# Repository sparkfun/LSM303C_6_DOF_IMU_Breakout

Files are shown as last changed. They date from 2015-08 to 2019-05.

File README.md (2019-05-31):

SparkFun LSM303C 6 DOF IMU Breakout
========================================

LSM303C Breakout (https://www.sparkfun.com/products/13303)

*[SparkFun LSM303C 6 DOF IMU Breakout (BOB-13303)](https://www.sparkfun.com/products/13303)*

The LSM303C is a triple axis accelerometer and triple axis magnetic sensor, providing 6D of orientation detection.

This part was created in Eagle v7.4.0

Repository Contents
-------------------

* **/Hardware** - All Eagle design files (.brd, .sch)
* **/Libraries** - All Arduino libraries and board examples
* **/Production** - Test bed files and production panel files

Documentation
--------------
* **[Arduino Library](https://github.com/sparkfun/SparkFun_LSM303C_6_DOF_IMU_Breakout_Arduino_Library)** - Arduino library for the LSM303C.
* **[Hookup Guide](https://learn.sparkfun.com/tutorials/lsm303c-6dof-hookup-guide)** - Basic hookup guide for the LSM303C.
* **[SparkFun Fritzing repo](https://github.com/sparkfun/Fritzing_Parts)** - Fritzing diagrams for SparkFun products.
* **[SparkFun 3D Model repo](https://github.com/sparkfun/3D_Models)** - 3D models of SparkFun products. 
* **[SparkFun Graphical Datasheets](https://github.com/sparkfun/Graphical_Datasheets)** -Graphical Datasheets for various SparkFun products

Product Versions
----------------
* [BOB-13303](https://www.sparkfun.com/products/13303)- LSM303C based 6 DOF IMU beakout board

Version History
---------------
* [v1.0_H1.0](https://github.com/sparkfun/LSM303C_6_DOF_IMU_Breakout/releases/tag/v1.0_H1.0) - Removing old libraries. Adding links to formal libs in readme.
* [v1.0](https://github.com/sparkfun/LSM303C_6_DOF_IMU_Breakout/releases/tag/v1.0) - First (hopefully ony) product release.  v10 is SFE code for version 1.0

License Information
-------------------

This product is _**open source**_! 

Please review the LICENSE.md file for license information. 

If you have any questions or concerns on licensing, please contact techsupport@sparkfun.com.

Distributed as-is; no warranty is given.

- Your friends at SparkFun.

_<COLLABORATION CREDIT>_

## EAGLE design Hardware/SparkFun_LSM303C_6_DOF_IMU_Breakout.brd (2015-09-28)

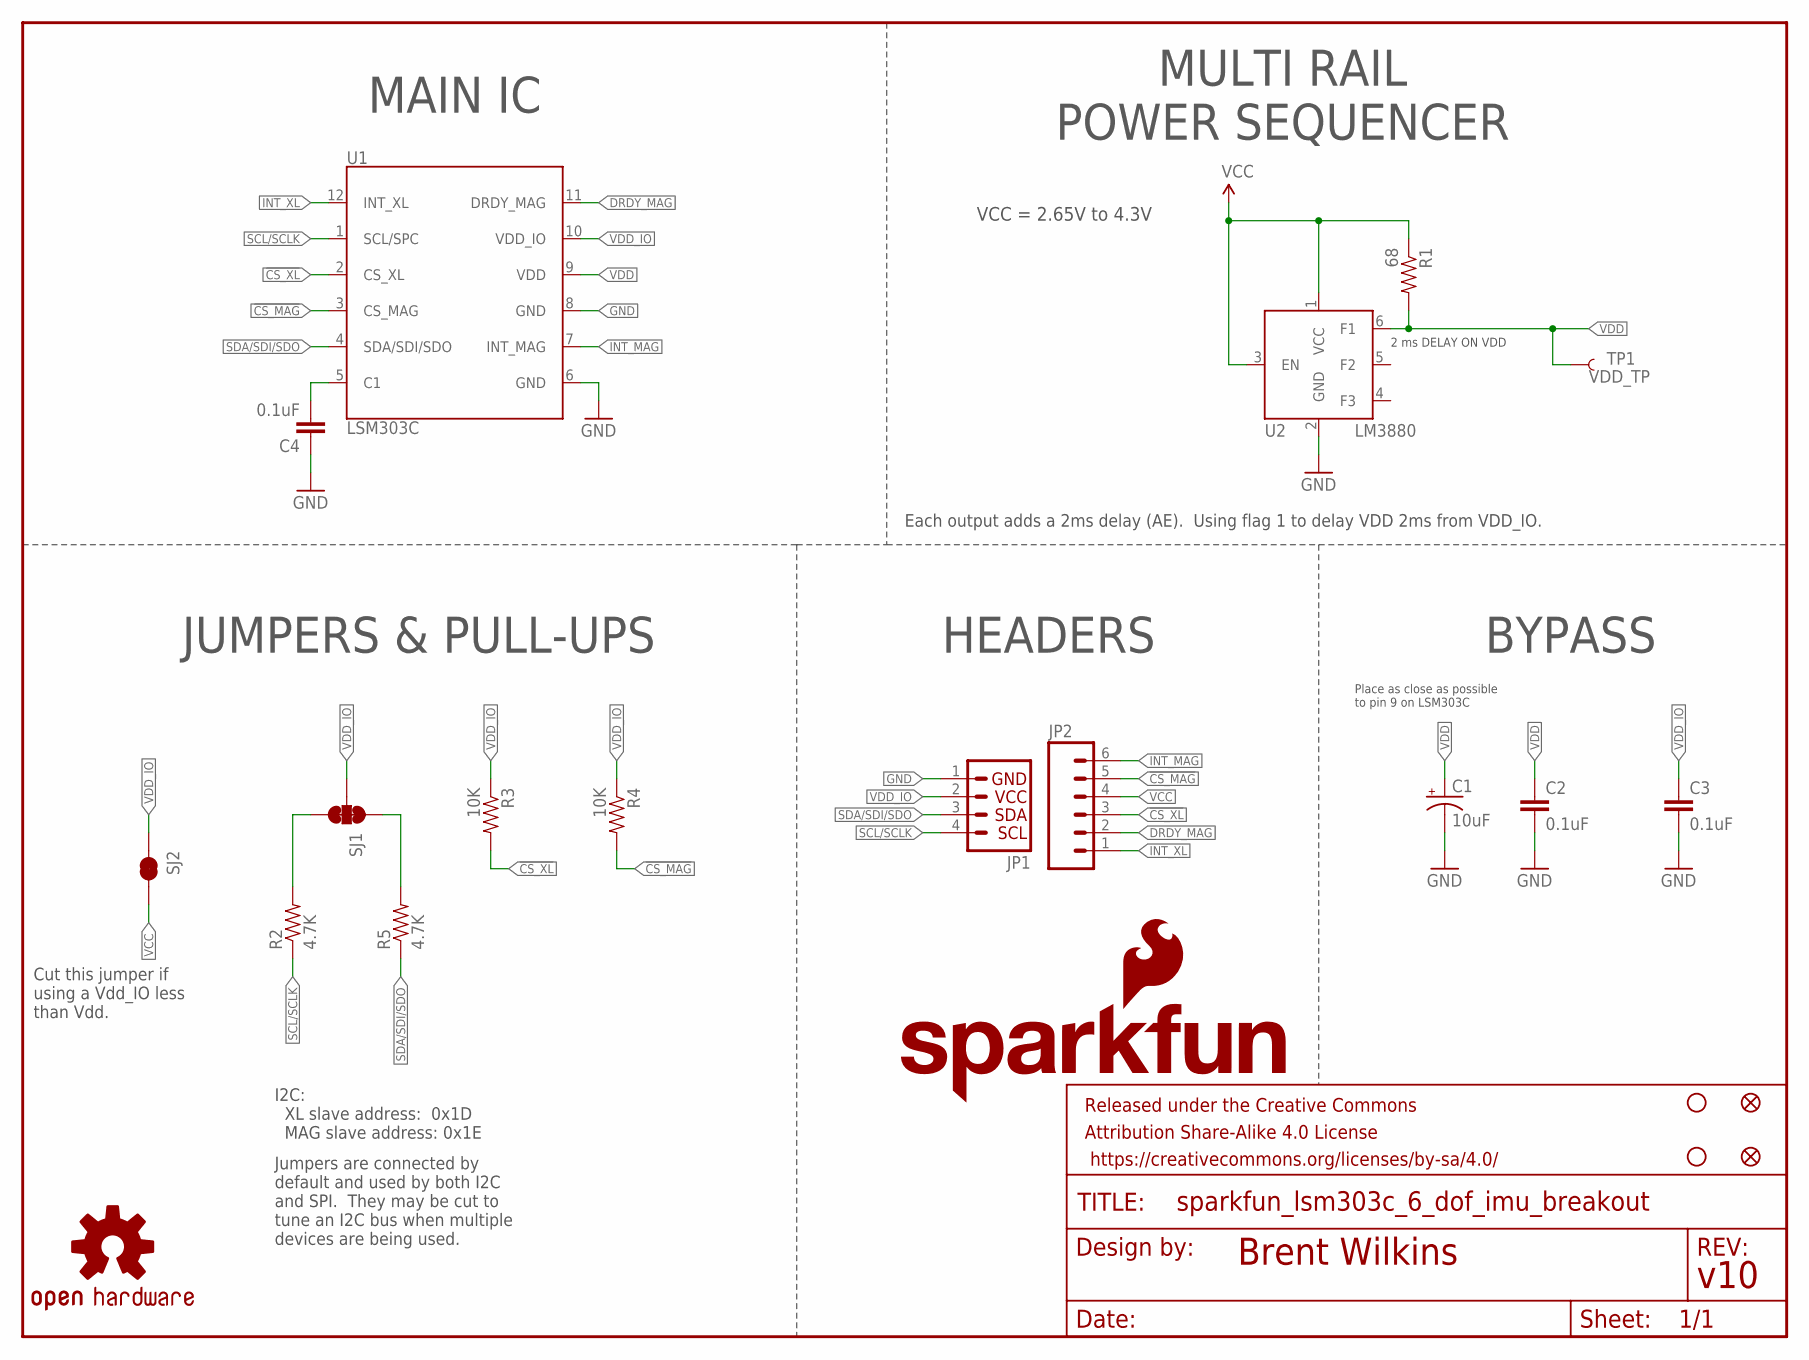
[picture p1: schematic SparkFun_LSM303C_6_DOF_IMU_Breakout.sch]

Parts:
C1: 10uF; EIA3216
C2, C3, C4: 0.1uF; 0603-CAP
FID1, FID2: FIDUCIAL1X2; FIDUCIAL-1X2
FRAME1: FRAME-LETTER; CREATIVE_COMMONS
JP1: I2C_STANDARD; 1X04
JP2: M06SILK_FEMALE_PTH; 1X06
LOGO1: SFE_LOGO_NAME.1_INCH; SFE_LOGO_NAME_.1
LOGO2: SFE_LOGO_FLAME.1EXP; SFE_LOGO_FLAME_COPPER_EXPOSED_.1
R1: 68; 0603-RES
R2, R5: 4.7K; 0603-RES
R3, R4: 10K; 0603-RES
SJ1: JUMPER-PAD-3-NC_BY_TRACE; PAD-JUMPER-3-3OF3_NC_BY_TRACE_YES_SILK_FULL_BOX
SJ2: JUMPER-PAD-2-NC_BY_TRACE; PAD-JUMPER-2-NC_BY_TRACE_YES_SILK
STANDOFF1, STANDOFF2: STAND-OFF
TP1: VDD_TP; TP_15TH
U1: LSM303C; LGA-12
U2: LM3880; SOT23-6
U$8: OSHW-LOGOS; OSHW-LOGO-S

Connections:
!CS_MAG: JP2.5, R4.2, U1.3 (CS_MAG)
!CS_XL: JP2.3, R3.2, U1.2 (CS_XL)
DRDY_MAG: JP2.2, U1.11 (DRDY_MAG)
GND: C1.C (-), C2.2, C3.2, C4.1, JP1.1, U1.6 (GND), U1.8 (GND), U2.2 (GND)
I2C-UP: R5.2, SJ1.1
INT_MAG: JP2.6, U1.7 (INT_MAG)
INT_XL: JP2.1, U1.12 (INT_XL)
unnamed: C4.2, U1.5 (C1)
unnamed: R2.2, SJ1.3
SCL/SCLK: JP1.4, R2.1, U1.1 (SCL/SPC)
SDA/SDI/SDO: JP1.3, R5.1, U1.4 (SDA/SDI/SDO)
VCC: JP2.4, R1.1, SJ2.2, U2.1 (VCC), U2.3 (EN)
VDD: C1.A (+), C2.1, R1.2, TP1.P$1, U1.9 (VDD), U2.6 (F1)
VDD_IO: C3.1, JP1.2, R3.1, R4.1, SJ1.2, SJ2.1, U1.10 (VDD_IO)

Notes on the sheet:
2 ms DELAY ON VDD
Place as close as possible to pin 9 on LSM303C
I2C: XL slave address: 0x1D MAG slave address: 0x1E
JUMPERS & PULL-UPS
HEADERS
BYPASS
MULTI RAIL POWER SEQUENCER
MAIN IC
Each output adds a 2ms delay (AE). Using flag 1 to delay VDD 2ms from VDD_IO.
Cut this jumper if using a Vdd_IO less than Vdd.
Jumpers are connected by default and used by both I2C and SPI. They may be cut to tune an I2C bus when multiple devices are being used.
VCC = 2.65V to 4.3V

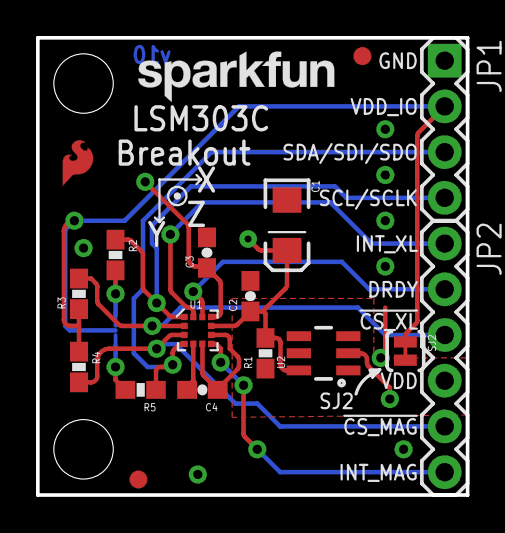
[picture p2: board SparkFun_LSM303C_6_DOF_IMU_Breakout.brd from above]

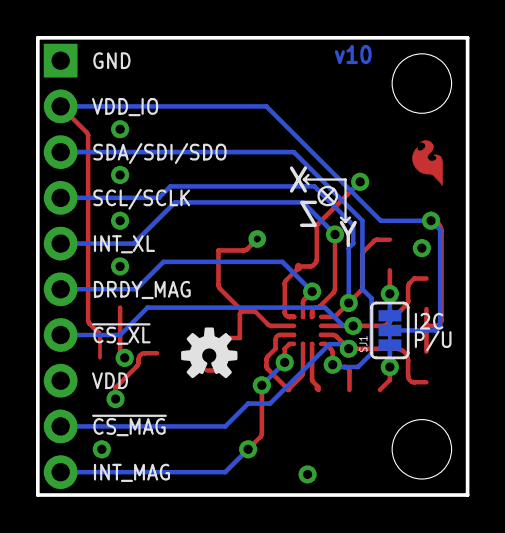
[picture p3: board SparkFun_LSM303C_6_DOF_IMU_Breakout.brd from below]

Board: 2 copper layers, 23.9 x 25.4 mm, 24 parts (2 on the bottom side), 14 nets.

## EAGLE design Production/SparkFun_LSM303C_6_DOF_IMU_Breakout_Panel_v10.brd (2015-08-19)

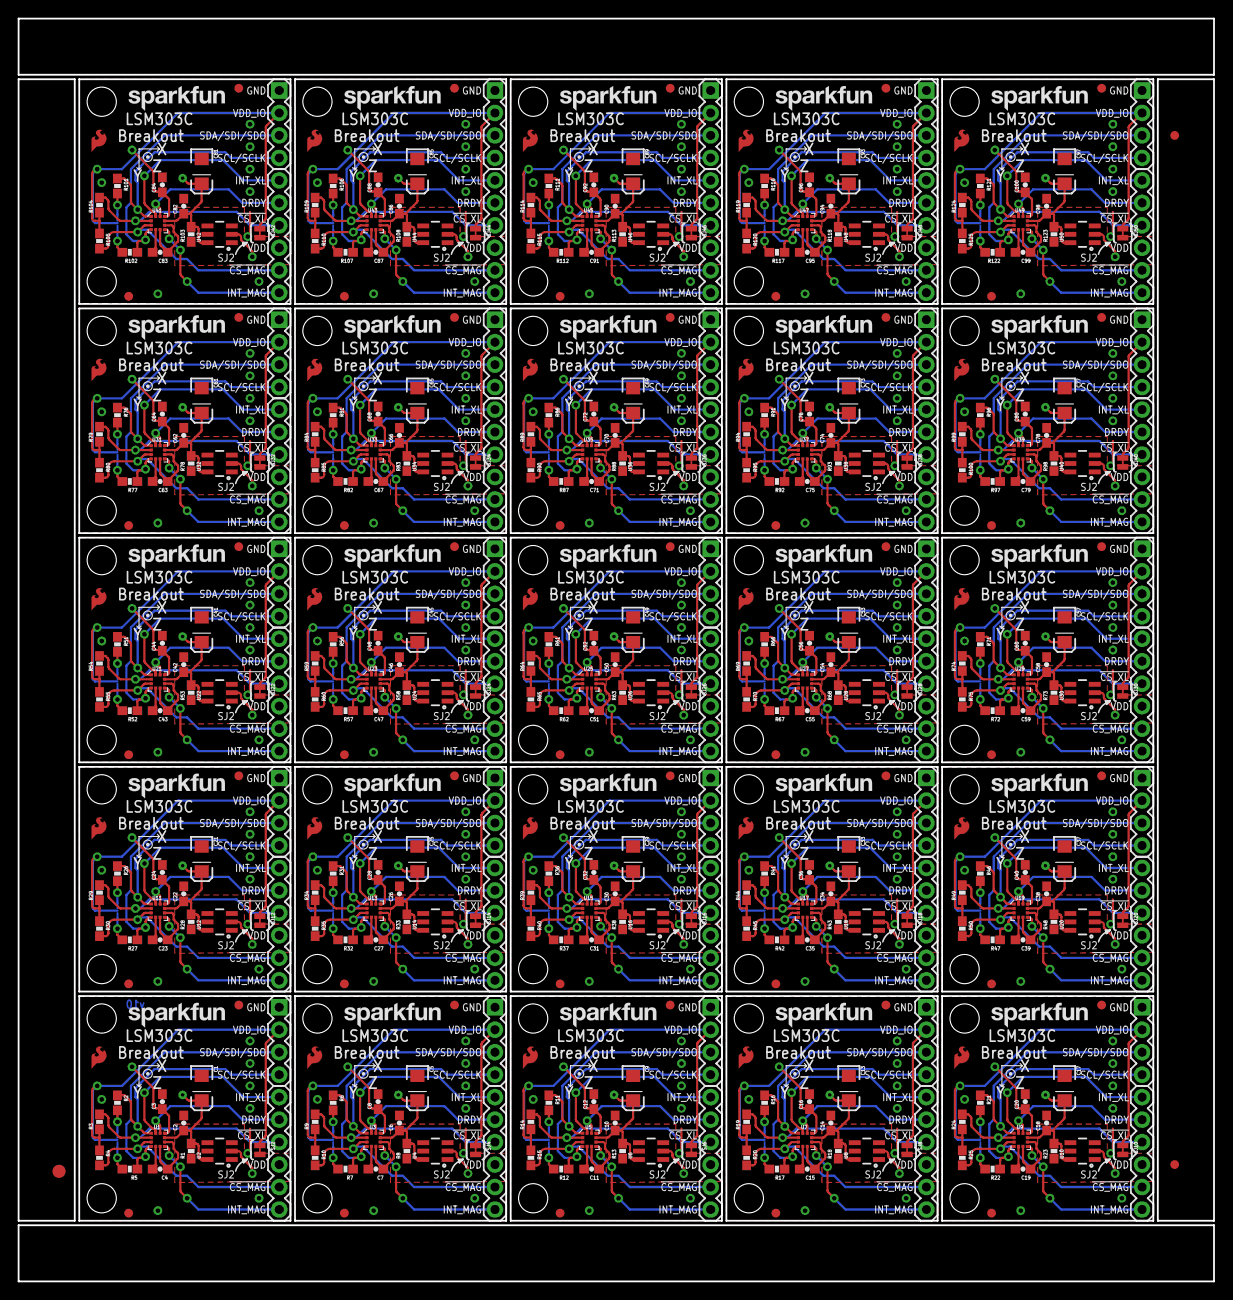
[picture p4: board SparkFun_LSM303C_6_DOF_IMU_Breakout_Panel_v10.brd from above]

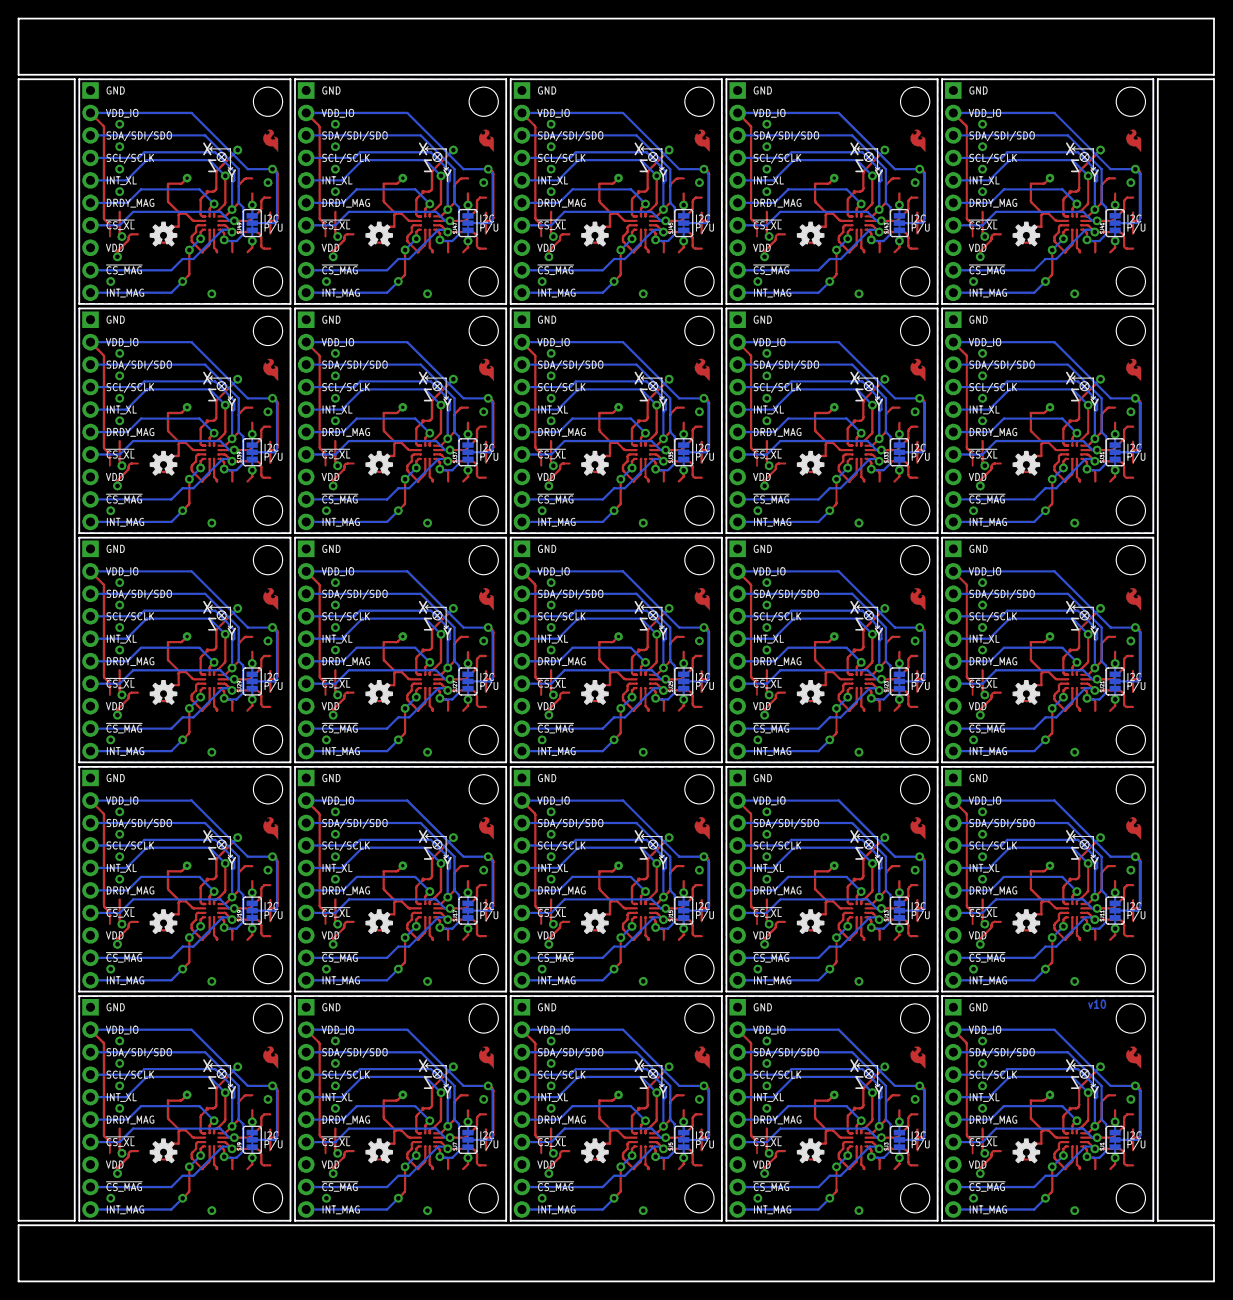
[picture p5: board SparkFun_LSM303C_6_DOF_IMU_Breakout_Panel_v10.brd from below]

Board: 2 copper layers, 135.1 x 142.7 mm, 578 parts (50 on the bottom side), 350 nets.

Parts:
C1, C5, C9, C13, C17, C21, C25, C29, C33, C37, C41, C45, C49, C53, C57, C61, C65, C69, C73, C77, C81, C85, C89, C93, C97: 10uF; EIA3216
C2, C3, C4, C6, C7, C8, C10, C11, C12, C14, C15, C16, C18, C19, C20, C22, C23, C24, C26, C27, C28, C30, C31, C32, C34, C35, C36, C38, C39, C40, C42, C43, C44, C46, C47, C48, C50, C51, C52, C54, C55, C56, C58, C59, C60, C62, C63, C64, C66, C67, C68, C70, C71, C72, C74, C75, C76, C78, C79, C80, C82, C83, C84, C86, C87, C88, C90, C91, C92, C94, C95, C96, C98, C99, C100: 0.1uF; 0603-CAP
E$1: FIDUCIAL-1.5X3
E$4, E$5: FIDUCIAL-1X2
FID1, FID2, FID3, FID4, FID5, FID6, FID7, FID8, FID9, FID10, FID11, FID12, FID13, FID14, FID15, FID16, FID17, FID18, FID19, FID20, FID21, FID22, FID23, FID24, FID25, FID26, FID27, FID28, FID29, FID30, FID31, FID32, FID33, FID34, FID35, FID36, FID37, FID38, FID39, FID40, FID41, FID42, FID43, FID44, FID45, FID46, FID47, FID48, FID49, FID50: FIDUCIAL1X2; FIDUCIAL-1X2
JP1, JP4, JP6, JP8, JP10, JP12, JP14, JP16, JP18, JP20, JP22, JP24, JP26, JP28, JP30, JP32, JP34, JP36, JP38, JP40, JP42, JP44, JP46, JP48, JP50: 1X04
JP2, JP3, JP5, JP7, JP9, JP11, JP13, JP15, JP17, JP19, JP21, JP23, JP25, JP27, JP29, JP31, JP33, JP35, JP37, JP39, JP41, JP43, JP45, JP47, JP49: 1X06
LOGO1, LOGO3, LOGO5, LOGO7, LOGO9, LOGO11, LOGO13, LOGO15, LOGO17, LOGO19, LOGO21, LOGO23, LOGO25, LOGO27, LOGO29, LOGO31, LOGO33, LOGO35, LOGO37, LOGO39, LOGO41, LOGO43, LOGO45, LOGO47, LOGO49: SFE_LOGO_NAME.1_INCH; SFE_LOGO_NAME_.1
LOGO2, LOGO4, LOGO6, LOGO8, LOGO10, LOGO12, LOGO14, LOGO16, LOGO18, LOGO20, LOGO22, LOGO24, LOGO26, LOGO28, LOGO30, LOGO32, LOGO34, LOGO36, LOGO38, LOGO40, LOGO42, LOGO44, LOGO46, LOGO48, LOGO50: SFE_LOGO_FLAME.1EXP; SFE_LOGO_FLAME_COPPER_EXPOSED_.1
R1, R8, R13, R18, R23, R28, R33, R38, R43, R48, R53, R58, R63, R68, R73, R78, R83, R88, R93, R98, R103, R108, R113, R118, R123: 68; 0603-RES
R2, R5, R6, R7, R11, R12, R16, R17, R21, R22, R26, R27, R31, R32, R36, R37, R41, R42, R46, R47, R51, R52, R56, R57, R61, R62, R66, R67, R71, R72, R76, R77, R81, R82, R86, R87, R91, R92, R96, R97, R101, R102, R106, R107, R111, R112, R116, R117, R121, R122: 4.7K; 0603-RES
R3, R4, R9, R10, R14, R15, R19, R20, R24, R25, R29, R30, R34, R35, R39, R40, R44, R45, R49, R50, R54, R55, R59, R60, R64, R65, R69, R70, R74, R75, R79, R80, R84, R85, R89, R90, R94, R95, R99, R100, R104, R105, R109, R110, R114, R115, R119, R120, R124, R125: 10K; 0603-RES
SJ1, SJ3, SJ5, SJ7, SJ9, SJ11, SJ13, SJ15, SJ17, SJ19, SJ21, SJ23, SJ25, SJ27, SJ29, SJ31, SJ33, SJ35, SJ37, SJ39, SJ41, SJ43, SJ45, SJ47, SJ49: PAD-JUMPER-3-3OF3_NC_BY_TRACE_YES_SILK_FULL_BOX
SJ2, SJ4, SJ6, SJ8, SJ10, SJ12, SJ14, SJ16, SJ18, SJ20, SJ22, SJ24, SJ26, SJ28, SJ30, SJ32, SJ34, SJ36, SJ38, SJ40, SJ42, SJ44, SJ46, SJ48, SJ50: JUMPER-PAD-2-NC_BY_TRACE; PAD-JUMPER-2-NC_BY_TRACE_YES_SILK
STANDOFF1, STANDOFF2, STANDOFF3, STANDOFF4, STANDOFF5, STANDOFF6, STANDOFF7, STANDOFF8, STANDOFF9, STANDOFF10, STANDOFF11, STANDOFF12, STANDOFF13, STANDOFF14, STANDOFF15, STANDOFF16, STANDOFF17, STANDOFF18, STANDOFF19, STANDOFF20, STANDOFF21, STANDOFF22, STANDOFF23, STANDOFF24, STANDOFF25, STANDOFF26, STANDOFF27, STANDOFF28, STANDOFF29, STANDOFF30, STANDOFF31, STANDOFF32, STANDOFF33, STANDOFF34, STANDOFF35, STANDOFF36, STANDOFF37, STANDOFF38, STANDOFF39, STANDOFF40, STANDOFF41, STANDOFF42, STANDOFF43, STANDOFF44, STANDOFF45, STANDOFF46, STANDOFF47, STANDOFF48, STANDOFF49, STANDOFF50: STAND-OFF
TP1, TP2, TP3, TP4, TP5, TP6, TP7, TP8, TP9, TP10, TP11, TP12, TP13, TP14, TP15, TP16, TP17, TP18, TP19, TP20, TP21, TP22, TP23, TP24, TP25: VDD_TP; TP_15TH
U1, U3, U5, U7, U9, U11, U13, U15, U17, U19, U21, U23, U25, U27, U29, U31, U33, U35, U37, U39, U41, U43, U45, U47, U49: LSM303C; LGA-12
U2, U4, U6, U8, U10, U12, U14, U16, U18, U20, U22, U24, U26, U28, U30, U32, U34, U36, U38, U40, U42, U44, U46, U48, U50: LM3880; SOT23-6
U$1, U$2, U$3, U$4, U$5, U$6, U$7, U$8, U$9, U$10, U$11, U$12, U$13, U$14, U$15, U$16, U$17, U$18, U$19, U$20, U$21, U$22, U$23, U$24, U$25: OSHW-LOGOS; OSHW-LOGO-S

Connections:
!CS_MAG: JP2.5, R4.2, U1.3
!CS_MAG1: JP3.5, R10.2, U3.3
!CS_MAG2: JP5.5, R15.2, U5.3
!CS_MAG3: JP7.5, R20.2, U7.3
!CS_MAG4: JP9.5, R25.2, U9.3
!CS_MAG5: JP11.5, R30.2, U11.3
!CS_MAG6: JP13.5, R35.2, U13.3
!CS_MAG7: JP15.5, R40.2, U15.3
!CS_MAG8: JP17.5, R45.2, U17.3
!CS_MAG9: JP19.5, R50.2, U19.3
!CS_MAG10: JP21.5, R55.2, U21.3
!CS_MAG11: JP23.5, R60.2, U23.3
!CS_MAG12: JP25.5, R65.2, U25.3
!CS_MAG13: JP27.5, R70.2, U27.3
!CS_MAG14: JP29.5, R75.2, U29.3
!CS_MAG15: JP31.5, R80.2, U31.3
!CS_MAG16: JP33.5, R85.2, U33.3
!CS_MAG17: JP35.5, R90.2, U35.3
!CS_MAG18: JP37.5, R95.2, U37.3
!CS_MAG19: JP39.5, R100.2, U39.3
!CS_MAG20: JP41.5, R105.2, U41.3
!CS_MAG21: JP43.5, R110.2, U43.3
!CS_MAG22: JP45.5, R115.2, U45.3
!CS_MAG23: JP47.5, R120.2, U47.3
!CS_MAG24: JP49.5, R125.2, U49.3
!CS_XL: JP2.3, R3.2, U1.2
!CS_XL1: JP3.3, R9.2, U3.2
!CS_XL2: JP5.3, R14.2, U5.2
!CS_XL3: JP7.3, R19.2, U7.2
!CS_XL4: JP9.3, R24.2, U9.2
!CS_XL5: JP11.3, R29.2, U11.2
!CS_XL6: JP13.3, R34.2, U13.2
!CS_XL7: JP15.3, R39.2, U15.2
!CS_XL8: JP17.3, R44.2, U17.2
!CS_XL9: JP19.3, R49.2, U19.2
!CS_XL10: JP21.3, R54.2, U21.2
!CS_XL11: JP23.3, R59.2, U23.2
!CS_XL12: JP25.3, R64.2, U25.2
!CS_XL13: JP27.3, R69.2, U27.2
!CS_XL14: JP29.3, R74.2, U29.2
!CS_XL15: JP31.3, R79.2, U31.2
!CS_XL16: JP33.3, R84.2, U33.2
!CS_XL17: JP35.3, R89.2, U35.2
!CS_XL18: JP37.3, R94.2, U37.2
!CS_XL19: JP39.3, R99.2, U39.2
!CS_XL20: JP41.3, R104.2, U41.2
!CS_XL21: JP43.3, R109.2, U43.2
!CS_XL22: JP45.3, R114.2, U45.2
!CS_XL23: JP47.3, R119.2, U47.2
!CS_XL24: JP49.3, R124.2, U49.2
DRDY_MAG: JP2.2, U1.11
DRDY_MAG1: JP3.2, U3.11
DRDY_MAG2: JP5.2, U5.11
DRDY_MAG3: JP7.2, U7.11
DRDY_MAG4: JP9.2, U9.11
DRDY_MAG5: JP11.2, U11.11
DRDY_MAG6: JP13.2, U13.11
DRDY_MAG7: JP15.2, U15.11
DRDY_MAG8: JP17.2, U17.11
DRDY_MAG9: JP19.2, U19.11
DRDY_MAG10: JP21.2, U21.11
DRDY_MAG11: JP23.2, U23.11
DRDY_MAG12: JP25.2, U25.11
DRDY_MAG13: JP27.2, U27.11
DRDY_MAG14: JP29.2, U29.11
DRDY_MAG15: JP31.2, U31.11
DRDY_MAG16: JP33.2, U33.11
DRDY_MAG17: JP35.2, U35.11
DRDY_MAG18: JP37.2, U37.11
DRDY_MAG19: JP39.2, U39.11
DRDY_MAG20: JP41.2, U41.11
DRDY_MAG21: JP43.2, U43.11
DRDY_MAG22: JP45.2, U45.11
DRDY_MAG23: JP47.2, U47.11
DRDY_MAG24: JP49.2, U49.11
GND: C1.C, C2.2, C3.2, C4.1, JP1.1, U1.6, U1.8, U2.2
GND1: C5.C, C6.2, C7.1, C8.2, JP4.1, U3.6, U3.8, U4.2
GND2: C9.C, C10.2, C11.1, C12.2, JP6.1, U5.6, U5.8, U6.2
GND3: C13.C, C14.2, C15.1, C16.2, JP8.1, U7.6, U7.8, U8.2
GND4: C17.C, C18.2, C19.1, C20.2, JP10.1, U9.6, U9.8, U10.2
GND5: C21.C, C22.2, C23.1, C24.2, JP12.1, U11.6, U11.8, U12.2
GND6: C25.C, C26.2, C27.1, C28.2, JP14.1, U13.6, U13.8, U14.2
GND7: C29.C, C30.2, C31.1, C32.2, JP16.1, U15.6, U15.8, U16.2
GND8: C33.C, C34.2, C35.1, C36.2, JP18.1, U17.6, U17.8, U18.2
GND9: C37.C, C38.2, C39.1, C40.2, JP20.1, U19.6, U19.8, U20.2
GND10: C41.C, C42.2, C43.1, C44.2, JP22.1, U21.6, U21.8, U22.2
GND11: C45.C, C46.2, C47.1, C48.2, JP24.1, U23.6, U23.8, U24.2
GND12: C49.C, C50.2, C51.1, C52.2, JP26.1, U25.6, U25.8, U26.2
GND13: C53.C, C54.2, C55.1, C56.2, JP28.1, U27.6, U27.8, U28.2
GND14: C57.C, C58.2, C59.1, C60.2, JP30.1, U29.6, U29.8, U30.2
GND15: C61.C, C62.2, C63.1, C64.2, JP32.1, U31.6, U31.8, U32.2
GND16: C65.C, C66.2, C67.1, C68.2, JP34.1, U33.6, U33.8, U34.2
GND17: C69.C, C70.2, C71.1, C72.2, JP36.1, U35.6, U35.8, U36.2
GND18: C73.C, C74.2, C75.1, C76.2, JP38.1, U37.6, U37.8, U38.2
GND19: C77.C, C78.2, C79.1, C80.2, JP40.1, U39.6, U39.8, U40.2
GND20: C81.C, C82.2, C83.1, C84.2, JP42.1, U41.6, U41.8, U42.2
GND21: C85.C, C86.2, C87.1, C88.2, JP44.1, U43.6, U43.8, U44.2
GND22: C89.C, C90.2, C91.1, C92.2, JP46.1, U45.6, U45.8, U46.2
GND23: C93.C, C94.2, C95.1, C96.2, JP48.1, U47.6, U47.8, U48.2
GND24: C97.C, C98.2, C99.1, C100.2, JP50.1, U49.6, U49.8, U50.2
I2C-UP: R5.2, SJ1.1
I2C-UP1: R7.2, SJ3.1
I2C-UP2: R12.2, SJ5.1
I2C-UP3: R17.2, SJ7.1
I2C-UP4: R22.2, SJ9.1
I2C-UP5: R27.2, SJ11.1
I2C-UP6: R32.2, SJ13.1
I2C-UP7: R37.2, SJ15.1
I2C-UP8: R42.2, SJ17.1
I2C-UP9: R47.2, SJ19.1
I2C-UP10: R52.2, SJ21.1
I2C-UP11: R57.2, SJ23.1
I2C-UP12: R62.2, SJ25.1
I2C-UP13: R67.2, SJ27.1
I2C-UP14: R72.2, SJ29.1
I2C-UP15: R77.2, SJ31.1
I2C-UP16: R82.2, SJ33.1
I2C-UP17: R87.2, SJ35.1
I2C-UP18: R92.2, SJ37.1
I2C-UP19: R97.2, SJ39.1
I2C-UP20: R102.2, SJ41.1
I2C-UP21: R107.2, SJ43.1
I2C-UP22: R112.2, SJ45.1
I2C-UP23: R117.2, SJ47.1
I2C-UP24: R122.2, SJ49.1
INT_MAG: JP2.6, U1.7
INT_MAG1: JP3.6, U3.7
INT_MAG2: JP5.6, U5.7
INT_MAG3: JP7.6, U7.7
INT_MAG4: JP9.6, U9.7
INT_MAG5: JP11.6, U11.7
INT_MAG6: JP13.6, U13.7
INT_MAG7: JP15.6, U15.7
INT_MAG8: JP17.6, U17.7
INT_MAG9: JP19.6, U19.7
INT_MAG10: JP21.6, U21.7
INT_MAG11: JP23.6, U23.7
INT_MAG12: JP25.6, U25.7
INT_MAG13: JP27.6, U27.7
INT_MAG14: JP29.6, U29.7
INT_MAG15: JP31.6, U31.7
INT_MAG16: JP33.6, U33.7
INT_MAG17: JP35.6, U35.7
INT_MAG18: JP37.6, U37.7
INT_MAG19: JP39.6, U39.7
INT_MAG20: JP41.6, U41.7
INT_MAG21: JP43.6, U43.7
INT_MAG22: JP45.6, U45.7
INT_MAG23: JP47.6, U47.7
INT_MAG24: JP49.6, U49.7
INT_XL: JP2.1, U1.12
INT_XL1: JP3.1, U3.12
INT_XL2: JP5.1, U5.12
INT_XL3: JP7.1, U7.12
INT_XL4: JP9.1, U9.12
INT_XL5: JP11.1, U11.12
INT_XL6: JP13.1, U13.12
INT_XL7: JP15.1, U15.12
INT_XL8: JP17.1, U17.12
INT_XL9: JP19.1, U19.12
INT_XL10: JP21.1, U21.12
INT_XL11: JP23.1, U23.12
INT_XL12: JP25.1, U25.12
INT_XL13: JP27.1, U27.12
INT_XL14: JP29.1, U29.12
INT_XL15: JP31.1, U31.12
INT_XL16: JP33.1, U33.12
INT_XL17: JP35.1, U35.12
INT_XL18: JP37.1, U37.12
INT_XL19: JP39.1, U39.12
INT_XL20: JP41.1, U41.12
INT_XL21: JP43.1, U43.12
INT_XL22: JP45.1, U45.12
INT_XL23: JP47.1, U47.12
INT_XL24: JP49.1, U49.12
unnamed: C4.2, U1.5
unnamed: R2.2, SJ1.3
unnamed: C7.2, U3.5
unnamed: R6.2, SJ3.3
unnamed: C11.2, U5.5
unnamed: R11.2, SJ5.3
unnamed: C15.2, U7.5
unnamed: R16.2, SJ7.3
unnamed: C19.2, U9.5
unnamed: R21.2, SJ9.3
unnamed: C23.2, U11.5
unnamed: R26.2, SJ11.3
unnamed: C27.2, U13.5
unnamed: R31.2, SJ13.3
unnamed: C31.2, U15.5
unnamed: R36.2, SJ15.3
unnamed: C35.2, U17.5
unnamed: R41.2, SJ17.3
unnamed: C39.2, U19.5
unnamed: R46.2, SJ19.3
unnamed: C43.2, U21.5
unnamed: R51.2, SJ21.3
unnamed: C47.2, U23.5
unnamed: R56.2, SJ23.3
unnamed: C51.2, U25.5
unnamed: R61.2, SJ25.3
unnamed: C55.2, U27.5
unnamed: R66.2, SJ27.3
unnamed: C59.2, U29.5
unnamed: R71.2, SJ29.3
unnamed: C63.2, U31.5
unnamed: R76.2, SJ31.3
unnamed: C67.2, U33.5
unnamed: R81.2, SJ33.3
unnamed: C71.2, U35.5
unnamed: R86.2, SJ35.3
unnamed: C75.2, U37.5
unnamed: R91.2, SJ37.3
unnamed: C79.2, U39.5
unnamed: R96.2, SJ39.3
unnamed: C83.2, U41.5
unnamed: R101.2, SJ41.3
unnamed: C87.2, U43.5
unnamed: R106.2, SJ43.3
unnamed: C91.2, U45.5
unnamed: R111.2, SJ45.3
unnamed: C95.2, U47.5
unnamed: R116.2, SJ47.3
unnamed: C99.2, U49.5
unnamed: R121.2, SJ49.3
SCL/SCLK: JP1.4, R2.1, U1.1
SCL/SCLK1: JP4.4, R6.1, U3.1
SCL/SCLK2: JP6.4, R11.1, U5.1
SCL/SCLK3: JP8.4, R16.1, U7.1
SCL/SCLK4: JP10.4, R21.1, U9.1
SCL/SCLK5: JP12.4, R26.1, U11.1
SCL/SCLK6: JP14.4, R31.1, U13.1
SCL/SCLK7: JP16.4, R36.1, U15.1
SCL/SCLK8: JP18.4, R41.1, U17.1
SCL/SCLK9: JP20.4, R46.1, U19.1
SCL/SCLK10: JP22.4, R51.1, U21.1
SCL/SCLK11: JP24.4, R56.1, U23.1
SCL/SCLK12: JP26.4, R61.1, U25.1
SCL/SCLK13: JP28.4, R66.1, U27.1
SCL/SCLK14: JP30.4, R71.1, U29.1
SCL/SCLK15: JP32.4, R76.1, U31.1
SCL/SCLK16: JP34.4, R81.1, U33.1
SCL/SCLK17: JP36.4, R86.1, U35.1
SCL/SCLK18: JP38.4, R91.1, U37.1
SCL/SCLK19: JP40.4, R96.1, U39.1
SCL/SCLK20: JP42.4, R101.1, U41.1
SCL/SCLK21: JP44.4, R106.1, U43.1
SCL/SCLK22: JP46.4, R111.1, U45.1
SCL/SCLK23: JP48.4, R116.1, U47.1
SCL/SCLK24: JP50.4, R121.1, U49.1
SDA/SDI/SDO: JP1.3, R5.1, U1.4
SDA/SDI/SDO1: JP4.3, R7.1, U3.4
SDA/SDI/SDO2: JP6.3, R12.1, U5.4
SDA/SDI/SDO3: JP8.3, R17.1, U7.4
SDA/SDI/SDO4: JP10.3, R22.1, U9.4
SDA/SDI/SDO5: JP12.3, R27.1, U11.4
SDA/SDI/SDO6: JP14.3, R32.1, U13.4
SDA/SDI/SDO7: JP16.3, R37.1, U15.4
SDA/SDI/SDO8: JP18.3, R42.1, U17.4
SDA/SDI/SDO9: JP20.3, R47.1, U19.4
SDA/SDI/SDO10: JP22.3, R52.1, U21.4
SDA/SDI/SDO11: JP24.3, R57.1, U23.4
SDA/SDI/SDO12: JP26.3, R62.1, U25.4
SDA/SDI/SDO13: JP28.3, R67.1, U27.4
SDA/SDI/SDO14: JP30.3, R72.1, U29.4
SDA/SDI/SDO15: JP32.3, R77.1, U31.4
SDA/SDI/SDO16: JP34.3, R82.1, U33.4
SDA/SDI/SDO17: JP36.3, R87.1, U35.4
SDA/SDI/SDO18: JP38.3, R92.1, U37.4
SDA/SDI/SDO19: JP40.3, R97.1, U39.4
SDA/SDI/SDO20: JP42.3, R102.1, U41.4
SDA/SDI/SDO21: JP44.3, R107.1, U43.4
SDA/SDI/SDO22: JP46.3, R112.1, U45.4
SDA/SDI/SDO23: JP48.3, R117.1, U47.4
SDA/SDI/SDO24: JP50.3, R122.1, U49.4
VCC: JP2.4, R1.1, SJ2.2, U2.1, U2.3
VCC1: JP3.4, R8.1, SJ4.2, U4.1, U4.3
VCC2: JP5.4, R13.1, SJ6.2, U6.1, U6.3
VCC3: JP7.4, R18.1, SJ8.2, U8.1, U8.3
VCC4: JP9.4, R23.1, SJ10.2, U10.1, U10.3
VCC5: JP11.4, R28.1, SJ12.2, U12.1, U12.3
VCC6: JP13.4, R33.1, SJ14.2, U14.1, U14.3
VCC7: JP15.4, R38.1, SJ16.2, U16.1, U16.3
VCC8: JP17.4, R43.1, SJ18.2, U18.1, U18.3
VCC9: JP19.4, R48.1, SJ20.2, U20.1, U20.3
VCC10: JP21.4, R53.1, SJ22.2, U22.1, U22.3
VCC11: JP23.4, R58.1, SJ24.2, U24.1, U24.3
VCC12: JP25.4, R63.1, SJ26.2, U26.1, U26.3
VCC13: JP27.4, R68.1, SJ28.2, U28.1, U28.3
VCC14: JP29.4, R73.1, SJ30.2, U30.1, U30.3
VCC15: JP31.4, R78.1, SJ32.2, U32.1, U32.3
VCC16: JP33.4, R83.1, SJ34.2, U34.1, U34.3
VCC17: JP35.4, R88.1, SJ36.2, U36.1, U36.3
VCC18: JP37.4, R93.1, SJ38.2, U38.1, U38.3
VCC19: JP39.4, R98.1, SJ40.2, U40.1, U40.3
VCC20: JP41.4, R103.1, SJ42.2, U42.1, U42.3
VCC21: JP43.4, R108.1, SJ44.2, U44.1, U44.3
VCC22: JP45.4, R113.1, SJ46.2, U46.1, U46.3
VCC23: JP47.4, R118.1, SJ48.2, U48.1, U48.3
VCC24: JP49.4, R123.1, SJ50.2, U50.1, U50.3
VDD: C1.A, C2.1, R1.2, TP1.P$1, U1.9, U2.6
VDD1: C5.A, C6.1, R8.2, TP2.P$1, U3.9, U4.6
VDD2: C9.A, C10.1, R13.2, TP3.P$1, U5.9, U6.6
VDD3: C13.A, C14.1, R18.2, TP4.P$1, U7.9, U8.6
VDD4: C17.A, C18.1, R23.2, TP5.P$1, U9.9, U10.6
VDD5: C21.A, C22.1, R28.2, TP6.P$1, U11.9, U12.6
VDD6: C25.A, C26.1, R33.2, TP7.P$1, U13.9, U14.6
VDD7: C29.A, C30.1, R38.2, TP8.P$1, U15.9, U16.6
VDD8: C33.A, C34.1, R43.2, TP9.P$1, U17.9, U18.6
VDD9: C37.A, C38.1, R48.2, TP10.P$1, U19.9, U20.6
VDD10: C41.A, C42.1, R53.2, TP11.P$1, U21.9, U22.6
VDD11: C45.A, C46.1, R58.2, TP12.P$1, U23.9, U24.6
VDD12: C49.A, C50.1, R63.2, TP13.P$1, U25.9, U26.6
VDD13: C53.A, C54.1, R68.2, TP14.P$1, U27.9, U28.6
VDD14: C57.A, C58.1, R73.2, TP15.P$1, U29.9, U30.6
VDD15: C61.A, C62.1, R78.2, TP16.P$1, U31.9, U32.6
VDD16: C65.A, C66.1, R83.2, TP17.P$1, U33.9, U34.6
VDD17: C69.A, C70.1, R88.2, TP18.P$1, U35.9, U36.6
VDD18: C73.A, C74.1, R93.2, TP19.P$1, U37.9, U38.6
VDD19: C77.A, C78.1, R98.2, TP20.P$1, U39.9, U40.6
VDD20: C81.A, C82.1, R103.2, TP21.P$1, U41.9, U42.6
VDD21: C85.A, C86.1, R108.2, TP22.P$1, U43.9, U44.6
VDD22: C89.A, C90.1, R113.2, TP23.P$1, U45.9, U46.6
VDD23: C93.A, C94.1, R118.2, TP24.P$1, U47.9, U48.6
VDD24: C97.A, C98.1, R123.2, TP25.P$1, U49.9, U50.6
VDD_IO: C3.1, JP1.2, R3.1, R4.1, SJ1.2, SJ2.1, U1.10
VDD_IO1: C8.1, JP4.2, R9.1, R10.1, SJ3.2, SJ4.1, U3.10
VDD_IO2: C12.1, JP6.2, R14.1, R15.1, SJ5.2, SJ6.1, U5.10
VDD_IO3: C16.1, JP8.2, R19.1, R20.1, SJ7.2, SJ8.1, U7.10
VDD_IO4: C20.1, JP10.2, R24.1, R25.1, SJ9.2, SJ10.1, U9.10
VDD_IO5: C24.1, JP12.2, R29.1, R30.1, SJ11.2, SJ12.1, U11.10
VDD_IO6: C28.1, JP14.2, R34.1, R35.1, SJ13.2, SJ14.1, U13.10
VDD_IO7: C32.1, JP16.2, R39.1, R40.1, SJ15.2, SJ16.1, U15.10
VDD_IO8: C36.1, JP18.2, R44.1, R45.1, SJ17.2, SJ18.1, U17.10
VDD_IO9: C40.1, JP20.2, R49.1, R50.1, SJ19.2, SJ20.1, U19.10
VDD_IO10: C44.1, JP22.2, R54.1, R55.1, SJ21.2, SJ22.1, U21.10
VDD_IO11: C48.1, JP24.2, R59.1, R60.1, SJ23.2, SJ24.1, U23.10
VDD_IO12: C52.1, JP26.2, R64.1, R65.1, SJ25.2, SJ26.1, U25.10
VDD_IO13: C56.1, JP28.2, R69.1, R70.1, SJ27.2, SJ28.1, U27.10
VDD_IO14: C60.1, JP30.2, R74.1, R75.1, SJ29.2, SJ30.1, U29.10
VDD_IO15: C64.1, JP32.2, R79.1, R80.1, SJ31.2, SJ32.1, U31.10
VDD_IO16: C68.1, JP34.2, R84.1, R85.1, SJ33.2, SJ34.1, U33.10
VDD_IO17: C72.1, JP36.2, R89.1, R90.1, SJ35.2, SJ36.1, U35.10
VDD_IO18: C76.1, JP38.2, R94.1, R95.1, SJ37.2, SJ38.1, U37.10
VDD_IO19: C80.1, JP40.2, R99.1, R100.1, SJ39.2, SJ40.1, U39.10
VDD_IO20: C84.1, JP42.2, R104.1, R105.1, SJ41.2, SJ42.1, U41.10
VDD_IO21: C88.1, JP44.2, R109.1, R110.1, SJ43.2, SJ44.1, U43.10
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

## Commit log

2015-02-13 Ready for proto review
    [SparkFun_LSM303C_6_DOF_IMU_Breakout.brd, SparkFun_LSM303C_6_DOF_IMU_Breakout.sch]
2015-02-13 Ready for final proto review
    [SparkFun_LSM303C_6_DOF_IMU_Breakout.brd, SparkFun_LSM303C_6_DOF_IMU_Breakout.sch]
2015-02-13 Added dimensions
    [SparkFun_LSM303C_6_DOF_IMU_Breakout.brd]
2015-02-17 Addded another mounting hole, removed documentation, & made I2C by default
    [SparkFun_LSM303C_6_DOF_IMU_Breakout.brd, SparkFun_LSM303C_6_DOF_IMU_Breakout.sch]
2015-02-17 Changed pullups abbreviation to P/U
    [SparkFun_LSM303C_6_DOF_IMU_Breakout.brd]
2015-02-18 Added PROD-IDs to all placed parts
    [SparkFun_LSM303C_6_DOF_IMU_Breakout.brd, SparkFun_LSM303C_6_DOF_IMU_Breakout.sch]
2015-02-19 Silk work
    [SparkFun_LSM303C_6_DOF_IMU_Breakout.brd, SparkFun_LSM303C_6_DOF_IMU_Breakout.sch]
2015-02-19 Closed VDD-VDD_IO jumper making the PCBA single input volatage (3.3V) by default
    [SparkFun_LSM303C_6_DOF_IMU_Breakout.brd, SparkFun_LSM303C_6_DOF_IMU_Breakout.sch]
2015-06-01 Fixed logic inversion bug and simplified board by removing jumpers
    [SparkFun_LSM303C_6_DOF_IMU_Breakout.brd, SparkFun_LSM303C_6_DOF_IMU_Breakout.sch]
2015-06-01 Updated SKU of 68Ω resistor
    [SparkFun_LSM303C_6_DOF_IMU_Breakout.brd, SparkFun_LSM303C_6_DOF_IMU_Breakout.sch]
2015-06-02 Small tweaks
    [SparkFun_LSM303C_6_DOF_IMU_Breakout.brd]
2015-06-02 Fixed 'width' dimension
    [SparkFun_LSM303C_6_DOF_IMU_Breakout.brd]
2015-06-02 Moved CS_XL out from under LSM303C
    [SparkFun_LSM303C_6_DOF_IMU_Breakout.brd]
2015-06-02 Moved CS_MAG out from under LSM303C
    [SparkFun_LSM303C_6_DOF_IMU_Breakout.brd]
2015-06-02 Straightened CS_MAG
    [SparkFun_LSM303C_6_DOF_IMU_Breakout.brd]
2015-06-02 Resolved QC issues
    [SparkFun_LSM303C_6_DOF_IMU_Breakout.brd, SparkFun_LSM303C_6_DOF_IMU_Breakout.sch]
2015-06-02 Adjusted trace under pad
    [SparkFun_LSM303C_6_DOF_IMU_Breakout.brd]
2015-08-12 Incremented version number
    [SparkFun_LSM303C_6_DOF_IMU_Breakout.brd, SparkFun_LSM303C_6_DOF_IMU_Breakout.sch]
2015-08-13 Renamed SJ4 & moved a dim to layer 47
    [SparkFun_LSM303C_6_DOF_IMU_Breakout.brd, SparkFun_LSM303C_6_DOF_IMU_Breakout.sch]
2015-08-14 Moved "inches note" to measures layer
    Moved "All units in inches" note from dimension to measures layer.
    [SparkFun_LSM303C_6_DOF_IMU_Breakout.brd]
2015-08-19 created panel v10
    [SparkFun_LSM303C_6_DOF_IMU_Breakout_Panel_v10.brd]
2015-09-28 Fixed typo in note
    [SparkFun_LSM303C_6_DOF_IMU_Breakout.brd, SparkFun_LSM303C_6_DOF_IMU_Breakout.sch]
2015-10-06 Squashed 'Libraries/Arduino/' content from commit f84d633
    git-subtree-dir: Libraries/Arduino
    git-subtree-split: f84d633edc27f09ee3d260810be5eb51c1b12e13
2015-12-22 Squashed 'Libraries/Arduino/' changes from f84d633..da3a509
    da3a509 Updated README with new release
    c6f465a Explicitly set the I2C speed to 400kHz
    git-subtree-split: da3a509b6cc8d50fff9ffc4cd9694e2ae8b64de5
    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
2015-12-22 Added subtree command to README & pulled in new Arduino library release
2019-05-31 Removing old libraries. Adding links to formal libs in readme.
    - Removing subtree and linking to Arduino library repo to keep up with the latest changes in code.

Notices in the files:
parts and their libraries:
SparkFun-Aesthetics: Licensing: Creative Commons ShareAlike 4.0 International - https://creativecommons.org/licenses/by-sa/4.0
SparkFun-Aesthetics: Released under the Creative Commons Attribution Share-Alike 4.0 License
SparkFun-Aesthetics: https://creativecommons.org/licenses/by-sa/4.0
